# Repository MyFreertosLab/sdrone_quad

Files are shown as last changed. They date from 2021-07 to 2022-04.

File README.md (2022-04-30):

ESP32 ESP-IDF Drone
===================

This is a Drone Implementation with esp-idf and esp32.
This software is under construction, but it works.

```
  git clone --recursive https://github.com/MyFreertosLab/sdrone_quad.git
  idf.py build
  idf.py flash
```
<h1>The first step</h1>
<p align="left">
  The hardware
  <p>Step 1: Minimal Hardware List</p>
</p>

1) The frame
2) RC TX/RX (I use FlySky I-BUS, but works well with PPM also)
3) PPM Encoder (if you not use FlySky I-Bus)
4) IMU (mpu9250) with at least accelerometer and gyroscope
5) Battery
6) Esc (30Ah)
7) Motors
8) Propellers
9) The Board (a simple ESP32 board)
10) Cup of coffee

<h1>The first test</h1>

Watch the video (https://youtube.com/shorts/mvMZztF52lA?feature=share)

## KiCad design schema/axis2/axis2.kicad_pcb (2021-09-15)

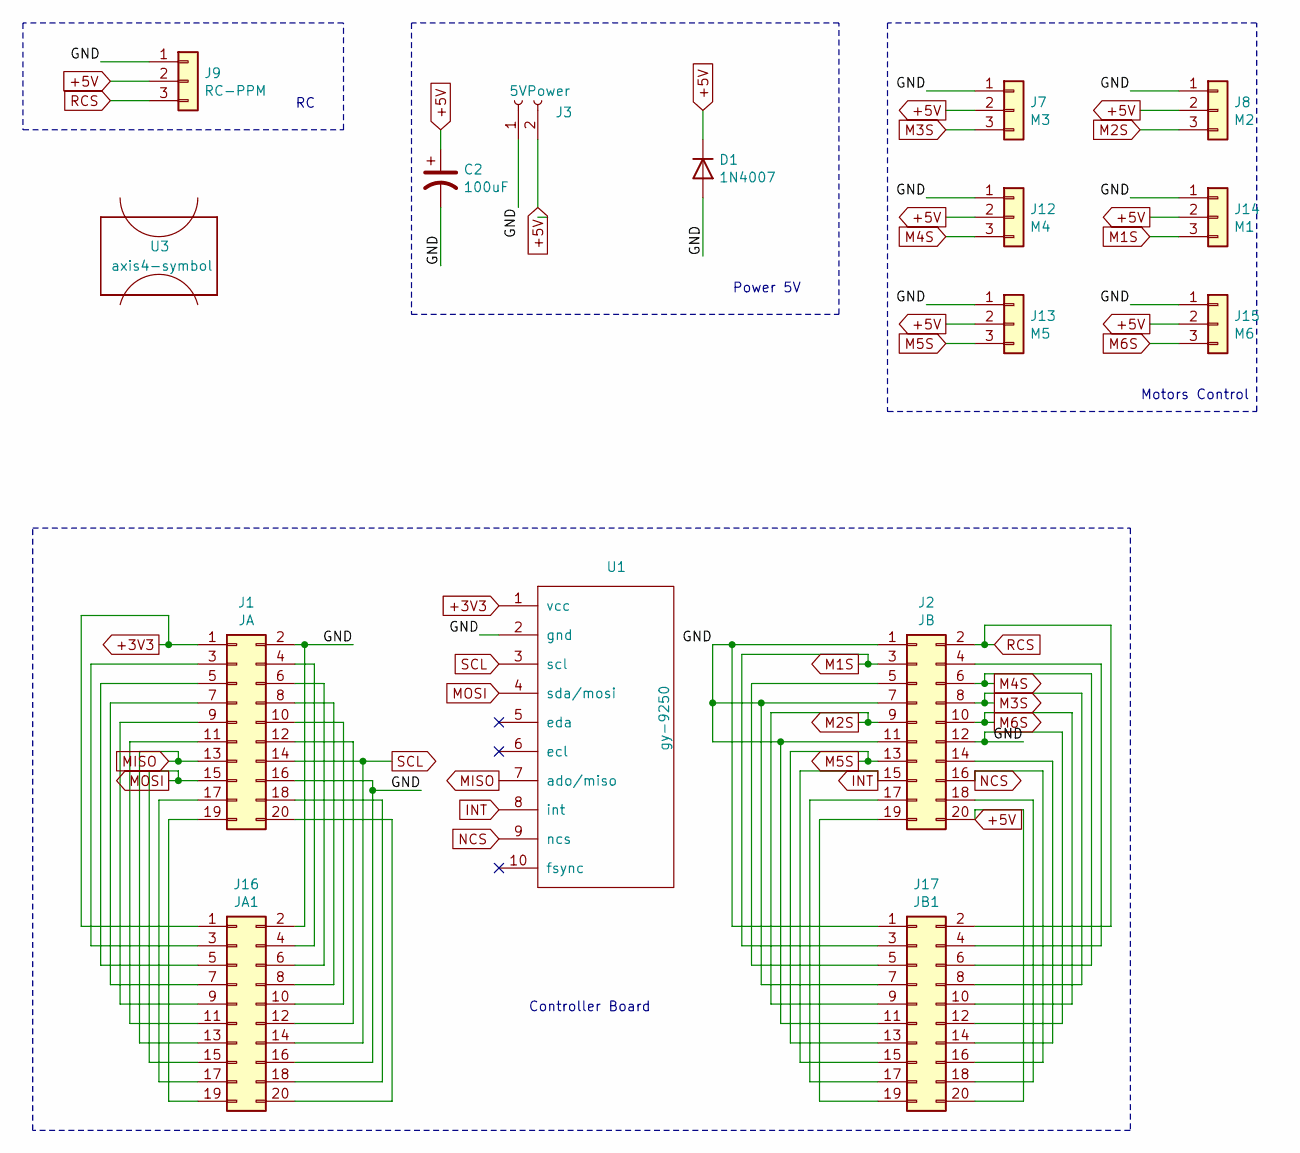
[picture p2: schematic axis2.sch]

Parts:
C2: 100uF; CP_Radial_D5.0mm_P2.50mm
D1: 1N4007; D_DO-41_SOD81_P10.16mm_Horizontal
J1: JA; PinSocket_2x10_P2.54mm_Vertical
J2: JB; PinSocket_2x10_P2.54mm_Vertical
J3: 5VPower; JST_XH_B2B-XH-AM_1x02_P2.50mm_Vertical
J7: M3; PinHeader_1x03_P2.54mm_Horizontal
J8: M2; PinHeader_1x03_P2.54mm_Horizontal
J9: RC-PPM; PinHeader_1x03_P2.54mm_Horizontal
J12: M4; PinHeader_1x03_P2.54mm_Horizontal
J13: M5; PinHeader_1x03_P2.54mm_Horizontal
J14: M1; PinHeader_1x03_P2.54mm_Horizontal
J15: M6; PinHeader_1x03_P2.54mm_Horizontal
J16: JA1; PinSocket_2x10_P2.54mm_Vertical
J17: JB1; PinSocket_2x10_P2.54mm_Vertical
U1: gy-9250
U3: axis4-symbol; axis4-frame

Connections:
+3V3: J1.1, J16.1, U1.1 (vcc)
+5V: C2.1, D1.1 (K), J2.20, J3.2, J7.2, J8.2, J9.2, J12.2, J13.2, J14.2, J15.2, J17.20
/GND: C2.2, D1.2 (A), J1.2, J1.16, J2.1, J2.7, J2.11, J2.12, J3.1, J7.1, J8.1, J9.1, J12.1, J13.1, J14.1, J15.1, J16.2, J16.16, J17.1, J17.7, J17.11, J17.12, U1.2 (gnd)
INT: J2.15, J17.15, U1.8 (int)
M1S: J2.3, J14.3, J17.3
M2S: J2.9, J8.3, J17.9
M3S: J2.8, J7.3, J17.8
M4S: J2.6, J12.3, J17.6
M5S: J2.13, J13.3, J17.13
M6S: J2.10, J15.3, J17.10
MISO: J1.13, J16.13, U1.7 (ado/miso)
MOSI: J1.15, J16.15, U1.4 (sda/mosi)
NCS: J2.16, J17.16, U1.9 (ncs)
unnamed: J1.3, J16.3
unnamed: J1.4, J16.4
unnamed: J1.5, J16.5
unnamed: J1.6, J16.6
unnamed: J1.7, J16.7
unnamed: J1.8, J16.8
unnamed: J1.9, J16.9
unnamed: J1.10, J16.10
unnamed: J1.11, J16.11
unnamed: J1.12, J16.12
unnamed: J1.17, J16.17
unnamed: J1.18, J16.18
unnamed: J1.19, J16.19
unnamed: J1.20, J16.20
unnamed: J2.4, J17.4
unnamed: J2.5, J17.5
unnamed: J2.14, J17.14
unnamed: J2.17, J17.17
unnamed: J2.18, J17.18
unnamed: J2.19, J17.19
RCS: J2.2, J9.3, J17.2
SCL: J1.14, J16.14, U1.3 (scl)

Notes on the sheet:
Power 5V
Controller Board
Motors Control

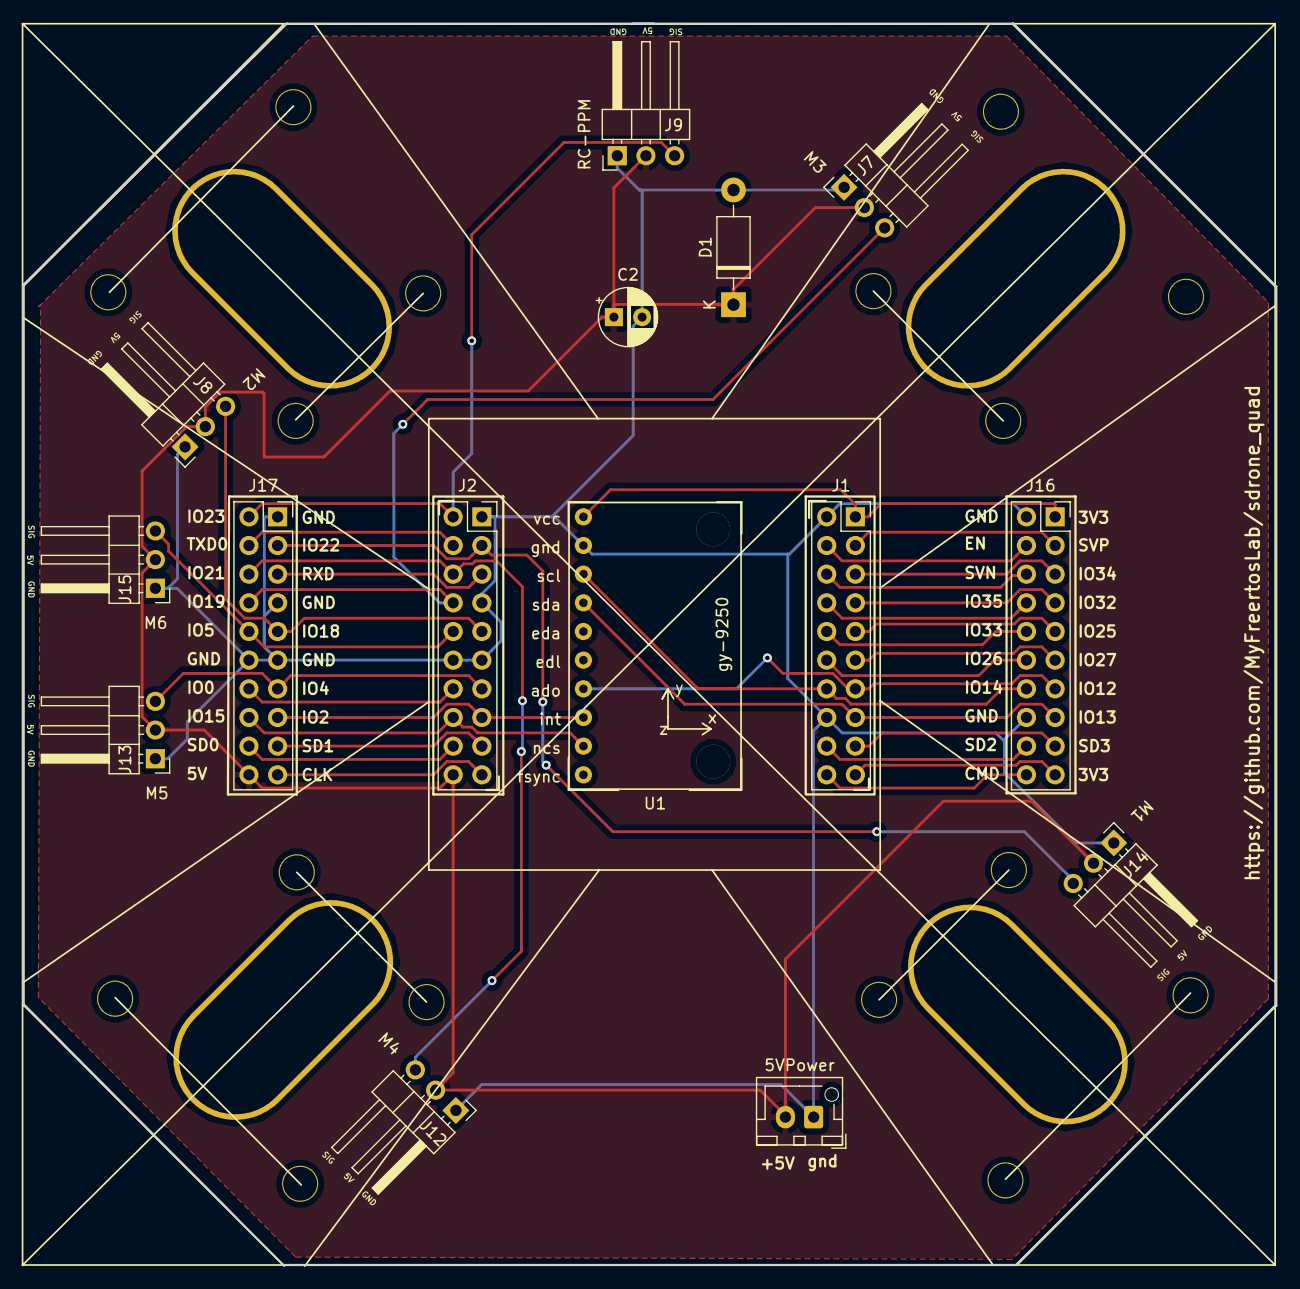
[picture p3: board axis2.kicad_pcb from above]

Board: 2 copper layers, 111.0 x 110.0 mm, 16 parts (0 on the bottom side), 35 nets.

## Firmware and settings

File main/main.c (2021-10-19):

#include "freertos/FreeRTOS.h"
#include "freertos/task.h"
#include <esp_system.h>
#include <nvs_flash.h>
#include <nvs.h>
#include <driver/i2c.h>
#include <sdrone_controller_task.h>
#include <sdrone_telemetry_task.h>

static sdrone_state_t sdrone_state;
static sdrone_state_handle_t sdrone_state_handle = &sdrone_state;
static TaskHandle_t controller_task_handle;
static TaskHandle_t motors_task_handle;
static TaskHandle_t rc_task_handle;
static TaskHandle_t imu_task_handle;

static TaskHandle_t telemetry_task_handle;
static sdrone_telemetry_task_state_t telemetry_state;
static sdrone_telemetry_task_state_handle_t telemetry_state_handle = &telemetry_state;

static esp_err_t my_i2c_init(int i2c_master_port) {
	i2c_config_t conf = {
	    .mode = I2C_MODE_MASTER,
	    .sda_io_num = GPIO_NUM_4,         // select GPIO specific to your project
	    .sda_pullup_en = GPIO_PULLUP_ENABLE,
	    .scl_io_num = GPIO_NUM_0,         // select GPIO specific to your project
	    .scl_pullup_en = GPIO_PULLUP_ENABLE,
	    .master.clk_speed = 400000,  // select frequency specific to your project
	    // .clk_flags = 0,          /*!< Optional, you can use I2C_SCLK_SRC_FLAG_* flags to choose i2c source clock here. */
	};
	ESP_ERROR_CHECK(i2c_param_config(i2c_master_port, &conf));
	ESP_ERROR_CHECK(i2c_driver_install(i2c_master_port, I2C_MODE_MASTER, 0,0,0));
	return ESP_OK;
}

esp_err_t my_nvs_init(){
    esp_err_t err = nvs_flash_init();
    if (err == ESP_ERR_NVS_NO_FREE_PAGES || err == ESP_ERR_NVS_NEW_VERSION_FOUND) {
        // NVS partition was truncated and needs to be erased
        // Retry nvs_flash_init
        ESP_ERROR_CHECK(nvs_flash_erase());
        err = nvs_flash_init();
    }
	return err;
}

void app_main(void)
{

	/*
	 * TODO: define component for hw initialization
	 */
	ESP_ERROR_CHECK(my_nvs_init());
	ESP_ERROR_CHECK(my_i2c_init(1));

	// init controller (this must be the first)
    xTaskCreate(sdrone_controller_task, "sdrone_controller_task", 4096, sdrone_state_handle, 8, &controller_task_handle);

    // init actuators
    xTaskCreate(sdrone_motors_task, "sdrone_motors_task", 4096, &(sdrone_state_handle->motors_state), 9, &motors_task_handle);

    // init sensors
    xTaskCreate(sdrone_rc_task, "sdrone_rc_task", 2048, &(sdrone_state_handle->rc_state), 5, &rc_task_handle);
    xTaskCreate(sdrone_imu_task, "sdrone_imu_task", 4096, &(sdrone_state_handle->imu_state), 10, &imu_task_handle);

    vTaskDelay(pdMS_TO_TICKS(100));

    sdrone_state_handle->motors_state.controller_task_handle = controller_task_handle;
    sdrone_state_handle->motors_state.driver_id = (uint32_t)SDRONE_MOTORS_DRIVER_ID;
    sdrone_state_handle->motors_state.controller_driver_id = (uint32_t)SDRONE_CONTROLLER_DRIVER_ID;

    sdrone_state_handle->rc_state.controller_task_handle = controller_task_handle;
    sdrone_state_handle->rc_state.driver_id = (uint32_t)SDRONE_RC_DRIVER_ID;
    sdrone_state_handle->rc_state.controller_driver_id = (uint32_t)SDRONE_CONTROLLER_DRIVER_ID;

    sdrone_state_handle->imu_state.controller_task_handle = controller_task_handle;
    sdrone_state_handle->imu_state.driver_id = (uint32_t)SDRONE_IMU_DRIVER_ID;
    sdrone_state_handle->imu_state.controller_driver_id = (uint32_t)SDRONE_CONTROLLER_DRIVER_ID;

    // Send notification to Controller.
	xTaskNotify(controller_task_handle,pdPASS,eSetValueWithOverwrite);

    // init telemetry
    vTaskDelay(pdMS_TO_TICKS(1000));
	telemetry_state_handle->controller_task_handle = controller_task_handle;
	telemetry_state_handle->controller_driver_id = (uint32_t)SDRONE_CONTROLLER_DRIVER_ID;
	telemetry_state_handle->sdrone_state_handle = sdrone_state_handle;
    xTaskCreate(sdrone_telemetry_task, "sdrone_telemetry_task", 4096, telemetry_state_handle, 5, &telemetry_task_handle);
	telemetry_state_handle->driver_id = (uint32_t)SDRONE_TELEMETRY_DRIVER_ID;
}

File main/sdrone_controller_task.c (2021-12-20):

/*
 * sdrone_controller_task.c
 *
 *  Created on: 18 mag 2021
 *      Author: andrea
 */
#include <stdio.h>
#include <stdlib.h>
#include <string.h>
#include <math.h>
#include <freertos/FreeRTOS.h>
#include <freertos/task.h>
#include <esp_system.h>
#include <sdrone_controller_task.h>
#include <sys/time.h>
#include <time.h>

void sdrone_controller_init(sdrone_state_handle_t sdrone_state_handle) {
	printf("sdrone_controller_init initial state\n");
	memset(sdrone_state_handle, 0, sizeof(*sdrone_state_handle));
	sdrone_state_handle->driver_id = (uint32_t) SDRONE_CONTROLLER_DRIVER_ID;

	// rotational
#ifdef SDRONE_DISABLE_ROLL
	sdrone_state_handle->controller_state[X_POS].pid_alfa.ke = 0.0f;
	sdrone_state_handle->controller_state[X_POS].pid_alfa.ki = 0.0f;
#else
	sdrone_state_handle->controller_state[X_POS].pid_alfa.ke = SDRONE_KE_ROLL;
	sdrone_state_handle->controller_state[X_POS].pid_alfa.ki = SDRONE_KI_ROLL;
#endif
#ifdef SDRONE_DISABLE_PITCH
	sdrone_state_handle->controller_state[Y_POS].pid_alfa.ke = 0.0f;
	sdrone_state_handle->controller_state[Y_POS].pid_alfa.ki = 0.0f;
#else
	sdrone_state_handle->controller_state[Y_POS].pid_alfa.ke = SDRONE_KE_PITCH;
	sdrone_state_handle->controller_state[Y_POS].pid_alfa.ki = SDRONE_KI_PITCH;
#endif

#ifdef SDRONE_DISABLE_YAW
	sdrone_state_handle->controller_state[Z_POS].pid_alfa.ke = 0.0f;
	sdrone_state_handle->controller_state[Z_POS].pid_alfa.ki = 0.0f;
#else
	sdrone_state_handle->controller_state[Z_POS].pid_alfa.ke = SDRONE_KE_Z;
	sdrone_state_handle->controller_state[Z_POS].pid_alfa.ki = SDRONE_KI_Z;
#endif

	// linear
#ifdef SDRONE_DISABLE_ACC
	sdrone_state_handle->controller_state[X_POS].pid_acc.ke = 0.0f;
	sdrone_state_handle->controller_state[X_POS].pid_acc.ki = 0.0f;
	sdrone_state_handle->controller_state[Y_POS].pid_acc.ke = 0.0f;
	sdrone_state_handle->controller_state[Y_POS].pid_acc.ki = 0.0f;
	sdrone_state_handle->controller_state[Z_POS].pid_acc.ke = 0.0f;
	sdrone_state_handle->controller_state[Z_POS].pid_acc.ki = 0.0f;
#else
	sdrone_state_handle->controller_state[X_POS].pid_acc.ke = SDRONE_KE_ACC;
	sdrone_state_handle->controller_state[X_POS].pid_acc.ki = SDRONE_KI_ACC;
	sdrone_state_handle->controller_state[Y_POS].pid_acc.ke = SDRONE_KE_ACC;
	sdrone_state_handle->controller_state[Y_POS].pid_acc.ki = SDRONE_KI_ACC;
	sdrone_state_handle->controller_state[Z_POS].pid_acc.ke = SDRONE_KE_ACC_Z;
	sdrone_state_handle->controller_state[Z_POS].pid_acc.ki = SDRONE_KI_ACC_Z;
#endif
}

uint16_t counter = 0;
void sdrone_controller_print_data(sdrone_state_handle_t sdrone_state_handle) {
	counter++;
	counter %= 500;
	if (counter == 0) {
		printf("RC: [%d,%d,%d,%d,%d,%d]\n",
				sdrone_state_handle->rc_state.rc_data.data.norm[RC_ROLL],
				sdrone_state_handle->rc_state.rc_data.data.norm[RC_PITCH],
				sdrone_state_handle->rc_state.rc_data.data.norm[RC_YAW],
				sdrone_state_handle->rc_state.rc_data.data.norm[RC_THROTTLE],
				sdrone_state_handle->rc_state.rc_data.data.norm[RC_SWA],
				sdrone_state_handle->rc_state.rc_data.data.norm[RC_SWB]);
		printf("U: DS[%d] RCS[%d] [%5.5f,%5.5f,%5.5f,%5.5f,%5.5f,%5.5f] YR:[%5.5f]\n",
				sdrone_state_handle->state,
				sdrone_state_handle->rc_state.rc_data.state,
				sdrone_state_handle->controller_state[X_POS].dynamic.U[SDRONE_UW_TETA_POS],
				sdrone_state_handle->controller_state[Y_POS].dynamic.U[SDRONE_UW_TETA_POS],
				sdrone_state_handle->controller_state[Z_POS].dynamic.U[SDRONE_UW_TETA_POS],
				sdrone_state_handle->controller_state[X_POS].dynamic.U[SDRONE_UW_ACC_POS],
				sdrone_state_handle->controller_state[Y_POS].dynamic.U[SDRONE_UW_ACC_POS],
				sdrone_state_handle->controller_state[Z_POS].dynamic.U[SDRONE_UW_ACC_POS],
				sdrone_state_handle->yaw_reference);
//		printf("W: [%5.5f,%5.5f,%5.5f,%5.5f]\n",
//				sdrone_state_handle->controller_state[0].dynamic.W[SDRONE_UW_TETA_POS],
//				sdrone_state_handle->controller_state[1].dynamic.W[SDRONE_UW_TETA_POS],
//				sdrone_state_handle->controller_state[2].dynamic.W[SDRONE_UW_TETA_POS],
//				sdrone_state_handle->controller_state[2].dynamic.W[SDRONE_UW_ACC_POS]);
		printf("RPY: [%5.5f,%5.5f,%5.5f]\n",
				sdrone_state_handle->imu_state.imu.data.gyro.rpy.xyz.x,
				sdrone_state_handle->imu_state.imu.data.gyro.rpy.xyz.y,
				sdrone_state_handle->imu_state.imu.data.gyro.rpy.xyz.z);
		printf("ACC: [%5.5f,%5.5f,%5.5f] [%5.5f,%5.5f,%5.5f]\n",
				sdrone_state_handle->imu_state.imu.data.accel.mss_if.array[X_POS],
				sdrone_state_handle->imu_state.imu.data.accel.mss_if.array[Y_POS],
				sdrone_state_handle->imu_state.imu.data.accel.mss_if.array[Z_POS],
				sdrone_state_handle->imu_state.imu.data.accel.rpy.xyz.x,
				sdrone_state_handle->imu_state.imu.data.accel.rpy.xyz.y,
				sdrone_state_handle->imu_state.imu.data.accel.rpy.xyz.z);
		printf("EACC: [%5.5f,%5.5f,%5.5f] [%5.5f,%5.5f,%5.5f] [%5.5f,%5.5f]\n",
				sdrone_state_handle->controller_state[X_POS].pid_acc.err,
				sdrone_state_handle->controller_state[Y_POS].pid_acc.err,
				sdrone_state_handle->controller_state[Z_POS].pid_acc.err,
				sdrone_state_handle->controller_state[X_POS].pid_acc.ierr,
				sdrone_state_handle->controller_state[Y_POS].pid_acc.ierr,
				sdrone_state_handle->controller_state[Z_POS].pid_acc.ierr,
				sdrone_state_handle->controller_state[Z_POS].pid_acc.ke,
				sdrone_state_handle->controller_state[Z_POS].pid_acc.ki
				);

//		printf("THR: [%d] p=[%5.5f],e=[%5.5f],v=[%5.5f]\n",
//				sdrone_state_handle->state,
//				sdrone_state_handle->controller_state[Z_POS].dynamic.predX[SDRONE_X_ACC_POS],
//				sdrone_state_handle->controller_state[Z_POS].pid_acc.err,
//				sdrone_state_handle->imu_state.imu.data.speed_if[Z_POS]);
		printf("DUT: [%5.5f, %5.5f, %5.5f, %5.5f]\n",
				sdrone_state_handle->motors_state.motors.motor[0].duty_cycle,
				sdrone_state_handle->motors_state.motors.motor[1].duty_cycle,
				sdrone_state_handle->motors_state.motors.motor[2].duty_cycle,
				sdrone_state_handle->motors_state.motors.motor[3].duty_cycle);

//		printf("ATT: [%5.5f,%5.5f,%5.5f]\n",
//				sdrone_state_handle->imu_state.imu.data.gravity_bf[X_POS],
//				sdrone_state_handle->imu_state.imu.data.gravity_bf[Y_POS],
//				sdrone_state_handle->imu_state.imu.data.gravity_bf[Z_POS]);
	}
}

bool sdrone_motors_are_armed(sdrone_state_handle_t sdrone_state_handle) {
	return (sdrone_state_handle->motors_state.motors.status == MOTORS_ARMED);
}

bool sdrone_motors_are_disarmed(sdrone_state_handle_t sdrone_state_handle) {
	return (sdrone_state_handle->motors_state.motors.status == MOTORS_DISARMED);
}
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

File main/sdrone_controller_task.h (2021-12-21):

/*
 * sdrone_controller_task.h
 *
 *  Created on: 18 mag 2021
 *      Author: andrea
 */

#ifndef MAIN_SDRONE_CONTROLLER_TASK_H_
#define MAIN_SDRONE_CONTROLLER_TASK_H_

#include <sdrone_motors_task.h>
#include <sdrone_rc_task.h>
#include <sdrone_imu_task.h>

//#define SDRONE_DEBUG_LOG
//#define SDRONE_DISABLE_ACC
//#define SDRONE_DISABLE_ROLL
//#define SDRONE_DISABLE_PITCH
//#define SDRONE_DISABLE_YAW
//#define SDRONE_ENABLE_TUNING_ACC
//#define SDRONE_ENABLE_TUNING_ACC_Z


#define SDRONE_MAX_ROLL_RADIANS  1.2217f // 70deg
#define SDRONE_MAX_PITCH_RADIANS  1.2217f // 70deg

#define SDRONE_ACCEL_MAX (3.667f*NUM_MOTORS)
#define SDRONE_ACCEL_MIN (2.0*SDRONE_GRAVITY_ACCELERATION-SDRONE_ACCEL_MAX)
#define SDRONE_ACCEL_RANGE (SDRONE_ACCEL_MAX - SDRONE_ACCEL_MIN)

#define SDRONE_NORM_THROTTLE_ZERO_RADIUS 50
#define SDRONE_NORM_THROTTLE_TO_ACCEL_FACTOR (((float)SDRONE_ACCEL_RANGE)/(float)(SDRONE_RC_CHANNEL_RANGE - SDRONE_NORM_THROTTLE_ZERO_RADIUS*2))
#define SDRONE_NORM_ROLL_TO_ACCEL_FACTOR ((float)SDRONE_ACCEL_RANGE/(float)SDRONE_RC_CHANNEL_RANGE)
#define SDRONE_NORM_PITCH_TO_ACCEL_FACTOR ((float)SDRONE_ACCEL_RANGE/(float)SDRONE_RC_CHANNEL_RANGE)

#define SDRONE_ACC_KE_MAX 2.0f
#define SDRONE_ACC_KE_MIN 0.0f
#define SDRONE_ACC_KI_MAX 0.1f
#define SDRONE_ACC_KI_MIN 0.0f
#define SDRONE_ACC_KE_RANGE  (SDRONE_ACC_KE_MAX - SDRONE_ACC_KE_MIN)
#define SDRONE_ACC_KI_RANGE  (SDRONE_ACC_KI_MAX - SDRONE_ACC_KI_MIN)
#define SDRONE_NORM_ACC_KE_FACTOR (SDRONE_ACC_KE_RANGE/(float)SDRONE_RC_CHANNEL_RANGE)
#define SDRONE_NORM_ACC_KI_FACTOR ((SDRONE_ACC_KI_RANGE)/(float)(SDRONE_RC_CHANNEL_RANGE))

#define SDRONE_ACC_KE_Z_MAX 2.0f
#define SDRONE_ACC_KE_Z_MIN 0.0f
#define SDRONE_ACC_KI_Z_MAX 0.1f
#define SDRONE_ACC_KI_Z_MIN 0.0f
#define SDRONE_ACC_KE_Z_RANGE  (SDRONE_ACC_KE_Z_MAX - SDRONE_ACC_KE_Z_MIN)
#define SDRONE_ACC_KI_Z_RANGE  (SDRONE_ACC_KI_Z_MAX - SDRONE_ACC_KI_Z_MIN)
#define SDRONE_NORM_ACC_KE_Z_FACTOR (SDRONE_ACC_KE_Z_RANGE/(float)SDRONE_RC_CHANNEL_RANGE)
#define SDRONE_NORM_ACC_KI_Z_FACTOR ((SDRONE_ACC_KI_Z_RANGE)/(float)(SDRONE_RC_CHANNEL_RANGE))

#define SDRONE_CONTROLLER_FREQ 100.0f
#define SDRONE_CONTROLLER_DT (1.0/SDRONE_CONTROLLER_FREQ)
#define SDRONE_CONTROLLER_DT2 (SDRONE_CONTROLLER_DT*SDRONE_CONTROLLER_DT)

// FIXME: togliere
#define SDRONE_NORM_ROLL_TO_RADIANS_FACTOR ((float)2.0*SDRONE_MAX_ROLL_RADIANS/(float)SDRONE_RC_CHANNEL_RANGE)
#define SDRONE_NORM_PITCH_TO_RADIANS_FACTOR ((float)2.0*SDRONE_MAX_PITCH_RADIANS/(float)SDRONE_RC_CHANNEL_RANGE)

// FIXME: togliere
#define SDRONE_CONTROLLER_REACTIVITY_DT (SDRONE_CONTROLLER_DT*10.0f)
#define SDRONE_REACTIVITY_FACTOR 1.5f

#define SDRONE_MAX_RADIANS_PER_SECOND 5.0f
#define SDRONE_MAX_W SDRONE_MAX_RADIANS_PER_SECOND*SDRONE_CONTROLLER_REACTIVITY_DT

#define SDRONE_MAX_YAW_RADIANS_PER_SECOND  0.79f // 45deg/s
#define SDRONE_NORM_YAW_TO_RADIANS_FACTOR ((float)2.0*SDRONE_MAX_YAW_RADIANS_PER_SECOND/(float)SDRONE_RC_CHANNEL_RANGE)
#define SDRONE_MAX_W_Z SDRONE_MAX_RADIANS_PER_SECOND*SDRONE_CONTROLLER_REACTIVITY_DT

#define SDRONE_LANDING_SPEED 0.15f

#define SDRONE_KE_ROLL  0.9f//0.7f
#define SDRONE_KI_ROLL  0.004f
#define SDRONE_KE_PITCH 0.7f//0.7f
#define SDRONE_KI_PITCH 0.004f
#define SDRONE_KE_Z     0.4f
#define SDRONE_KI_Z     0.002f

#define SDRONE_KE_ACC_Z     0.68f
#define SDRONE_KI_ACC_Z     0.004f
#define SDRONE_KE_ACC       0.0f
#define SDRONE_KI_ACC       0.0f

#define SDRONE_AXIS_LENGTH 0.20f
#define SDRONE_MASS 1.2f

#define SDRONE_X_TETA_POS    0
#define SDRONE_X_OMEGA_POS   1
#define SDRONE_X_ALFA_POS    2
#define SDRONE_X_SPEED_POS   3
#define SDRONE_X_ACC_POS     4

#define SDRONE_UW_TETA_POS   0
#define SDRONE_UW_ACC_POS    1

#define SDRONE_Y_TORQUE_POS  0
#define SDRONE_Y_ACC_POS     1

#define SDRONE_AXIS_X_POS    0
#define SDRONE_AXIS_Y_POS    1
#define SDRONE_AXIS_Z_POS    2

#define MOTORS_FRAME_X_QUADCOPTER
//#define MOTORS_FRAME_ONE_HORIZONTAL_AXIS
#ifdef MOTORS_FRAME_X_QUADCOPTER
#define SDRONE_NUM_MOTORS 4
#else
#ifdef MOTORS_FRAME_HORIZONTAL_HEXACOPTER
#define SDRONE_NUM_MOTORS 6
#else
#ifdef MOTORS_FRAME_ONE_HORIZONTAL_AXIS
#define SDRONE_NUM_MOTORS 2
#endif
#endif
#endif


typedef enum {
	SDRONE_MOTORS_DRIVER_ID = 1,
	SDRONE_RC_DRIVER_ID,
	SDRONE_IMU_DRIVER_ID,
	SDRONE_CONTROLLER_DRIVER_ID,
	SDRONE_TELEMETRY_DRIVER_ID
} sdrone_drivers_id;

typedef enum {
	SDRONE_OFF = 0,
	SDRONE_ON,
	SDRONE_TAKE_OFF,
	SDRONE_TAKEN_OFF,
	SDRONE_LANDING,
	SDRONE_LANDED
} sdrone_state_enum;

typedef struct {
	float err;
	float ierr;
	float derr;
	float prevErr;
	float correction;
	float ke;
	float ki;
	float kd;
} sdrone_pid_t;

typedef struct {
	float predX[5]; // [teta, omega, alfa, speed_bf, acc_bf] (rad, rad/s, rad/s^2, m/s^2, m/s)
	float X[5]; // [teta, omega, alfa, speed_bf, acc_bf] (rad, rad/s, rad/s^2, m/s, m/s^2)
	float U[2]; // [teta, acc_bf] (rad, m/s^2)
	float W[2]; // [dteta,dacc_bf] (rad, m/s^2)
	float Y[2]; // [torque, acc_bf](m*rad/s^2,m/s^2) NOTA: Y è accelerazione richiesta ai motori (diverso da 0 solo per asse Z)
} sdrone_dynamic_state_t;

typedef struct {
	sdrone_dynamic_state_t dynamic;
	sdrone_pid_t pid_alfa;
	sdrone_pid_t pid_acc;
} sdrone_dynamic_t;

typedef struct {
	sdrone_state_enum state;
	sdrone_motors_state_t motors_state;
	sdrone_rc_state_t rc_state;
	sdrone_imu_state_t imu_state;
	uint32_t driver_id;
	sdrone_dynamic_t controller_state[3]; // one for each axis x,y,z
	mpu9250_cossin_t cossin_target;
	float yaw_reference;
} sdrone_state_t;

typedef sdrone_state_t* sdrone_state_handle_t;

void sdrone_controller_task(void *arg);

#endif /* MAIN_SDRONE_CONTROLLER_TASK_H_ */

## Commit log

2021-07-16 Primo commit
    [axis2-B.Cu.gbl, axis2-B.Mask.gbs, axis2-B.Paste.gbp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]
2021-07-16 Aggiunto moduli driver
2021-07-19 Eliminato ciclo di misure
2021-08-14 Corretto scheda. Erano invertiti i pin degli headers
    [axis2-B.Cu.gbl, axis2-B.Cu.gbr, axis2-B.Mask.gbr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]
2021-09-05 Pull drivers
2021-09-06 Input motori: momentum & thrust
2021-09-09 Aggiunto at e thrust si stato dei motors
2021-09-11 Aggiunto bozza arm/disarm con gesture rc
2021-09-11 Aggiunto limiti motors in [0,4.4] newton
2021-09-11 Il controller corregge l'errore solo se thrust richiesto è maggiore di 2.0 newton
    [sdrone_controller_task.c, sdrone_controller_task.h]
2021-09-15 Tolto alimentazione 12V dalla scheda. Utilizzo alimentazione separata per i motori
    [axis2-B.Cu.gbr, axis2-B.Mask.gbr, axis2-B.Paste.gbr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]
2021-09-19 Pongo U = 0 in un intorno di RC = 0 per yaw,pitch,roll
2021-09-21 Aggiunto errore integrale e sistemato ke e ki. Volo quasi corretto ...
    [sdrone_controller_task.c, sdrone_controller_task.h, sdrone_motors_task.c]
2021-10-07 Integrato Magnetometer. Da provare
2021-11-01 Aggiunto script di formattazione sci dei dati di volo
2021-11-13 Calcolo dinamico zero accelerometro (per ora ad eliche ferme) e modificato range Thrust (-200,200)
2021-11-19 Aggiunto thrust nello stato X e nell'uscita Y
2021-11-21 Corretto condizione di attivazione della correzione e abbassato KE,KI
2021-11-22 Aggiunto offset per motori ed aggiunto evento di telemetria per soli dati z
2021-11-25 Messo a zero offset motori
2021-11-30 Bozza transizioni di stato sdrone e controllo accelerazione Z
2021-12-04 Aggiunto bozza conversioni geometriche accelerazioni e calcolo errori
    [sdrone_controller_task.c, sdrone_controller_task.h]
2021-12-04 rimesso integrale errori per RPY, ma non per accel
    [sdrone_controller_task.h]
2021-12-05 Iniziato prove di volo con controllo velocità veticale
2021-12-10 Aggiunto yaw_reference in sdrone_state ed aggiunto possibilità di disabilitare correzioni yaw, pitch, roll ed acc per permettere i test su ogni asse separatamente
2021-12-21 Aggiornato telemetria con wsserver ed eseguito rpove di volo
